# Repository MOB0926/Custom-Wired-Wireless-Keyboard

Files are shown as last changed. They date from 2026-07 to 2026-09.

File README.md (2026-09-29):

### Custom-Wired-Wireless-Keyboard

## What Is This?

- This is my entry for Hackclub's 'KEEB' YSWS

- I designed a Custom TKL keyboard. I designed a PCB and a 3D-Printed Case to house the PCB

- My keyboard features 80 Keys in the standard orientation and order of a keyboard. In addition to an EC11 Rotary encoder for Volume Adjustment and a 0.91 in OLED to display whatever I want. As the circuit is controlled by a WEMOS LOLIN ESP32 S3 Mini, I have included wireless functionality through its onboard BLE, along with an internal 18650 battery and charging unit to supply power during wireless use.

## Challenges 

- Price. PCBs over 100x100mm are very expensive, along with all the other components this may have been my most dificult project for finding cost effective solutions

- Size. The case is massive and no printer I own or have acces too will allow me to print this so I had to think about that as I designed.

- Procrastination. I had 3 months to do this and for some reason took like 3 week breaks in between entries at the begining

## What I learned

- This is my first time implementing a battery into a project so it was quite the new experience

- I have never designed or even built a Keyboard in my life (Excluding the Blueprint Hack-Pad) so I learnt a lot about how they work and the many different ways the case can come together.

- 3ple check every measurement before basing a design choice on it and then coming back after 4 hours of work just for it to be completetly wrong

## Why 

- Free Keyboard Obviously (Well if instead of putting all this time into this and I got a job instead I think I would have more than a $90 grant)

- Cool thing to show off

- Experience and knowledge for the future that will hopefully help me get a good career

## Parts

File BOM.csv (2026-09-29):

Item Desc | Link / Seller | qty | total price (USD)
Esp32-S3-Mini | https://www.aliexpress.com/item/3256805262904443.html?mp=1 | x1 | 06.39
Li-ion Bat Charger | https://www.aliexpress.com/item/3256806637067881.html?mp=1 | x1 | 02.75
1N148 Diodes SMD (100pc) | https://www.aliexpress.com/item/3256809295401623.html?mp=1 | x1 | 01.86
Switches (90pc) | https://www.aliexpress.com/item/3256806210108666.html?mp=1 | x1 | 13.21
Keycap Set (104pc) | https://www.aliexpress.com/item/3256811496795361.html?mp=1 | x1 | 08.12
M3x6 Screws (50pc) | https://www.aliexpress.com/item/3256808399236240.html?mp=1 | x1 | 00.99
EC11 Rotary Encoder | https://www.aliexpress.com/item/3256805940972786.html?mp=1 | x1 | 01.56
PCB (5pc) | JLCPCB.com | x1 | 26.90
Standofs (1x6.25u + 4x2u) | https://www.aliexpress.com/item/3256801500004993.html?mp=1 | x1 | 5.57
Shipping |  |  | 18.54
Total |  |  | 85.89

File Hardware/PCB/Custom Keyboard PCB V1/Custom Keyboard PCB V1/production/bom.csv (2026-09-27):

Designator | Footprint | Quantity | Value | LCSC Part #
D1, D10, D11, D12, D13, D14, D15, D16, D17, D18, D19, D2, D20, D21, D22, D23, D24, D25, D26, D27, D28, D29, D3, D30, D31, D32, D33, D34, D35, D36, D37, D38, D39, D4, D40, D41, D42, D43, D44, D45, D46, D47, D48, D49, D5, D50, D51, D52, D53, D54, D55, D56, D57, D58, D59, D6, D60, D61, D62, D63, D64, D65, D66, D67, D68, D69, D7, D70, D71, D72, D73, D74, D75, D76, D77, D78, D79, D8, D80, D9 | D_MiniMELF_Handsoldering | 80 | 1N4148
J1 | OLED_SSD1306_I2C_0.96 | 1 | Conn_01x04
J2, J3, J4, J5 | PinHeader_1x01_P2.54mm_Vertical | 4 | Conn_01x01
R1, R2, R3 | R_Axial_DIN0204_L3.6mm_D1.6mm_P5.08mm_Horizontal | 3 | 5k
S1, S2, S3, S4 | STAB_MX_P_2u | 4 | MX_stab
S5 | STAB_MX_P_6.25u | 1 | MX_stab
SW1, SW10, SW11, SW12, SW13, SW14, SW15, SW16, SW17, SW18, SW19, SW2, SW20, SW21, SW22, SW23, SW24, SW25, SW26, SW27, SW28, SW29, SW3, SW30, SW31, SW32, SW33, SW34, SW35, SW36, SW37, SW38, SW39, SW4, SW40, SW41, SW42, SW43, SW44, SW45, SW46, SW47, SW48, SW49, SW5, SW50, SW51, SW52, SW53, SW54, SW55, SW56, SW57, SW58, SW59, SW6, SW60, SW61, SW62, SW63, SW64, SW65, SW66, SW67, SW68, SW69, SW7, SW70, SW71, SW72, SW73, SW74, SW75, SW76, SW77, SW78, SW79, SW8, SW80, SW9 | SW_MX_1u | 80 | SW_Push
SW_EC11 | RotaryEncoder_Alps_EC11E-Switch_Vertical_H20mm_MountingHoles | 1 | RotaryEncoder_Switch_MP
U1 | WEMOS_S2_mini | 1 | WeMos_S3_mini

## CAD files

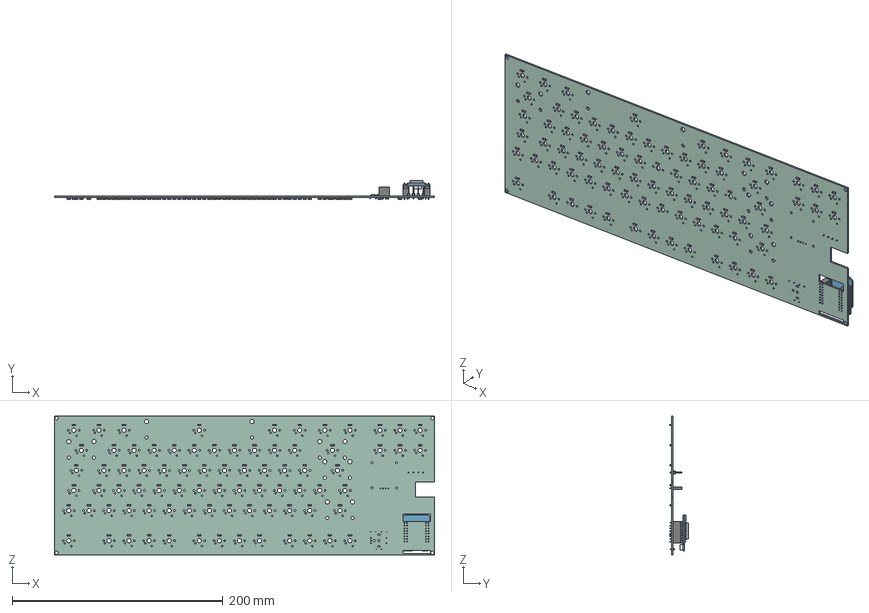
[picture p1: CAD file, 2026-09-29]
Hardware/Case/PCB 3D Model.step
360.5 x 17.7 x 131.8 mm

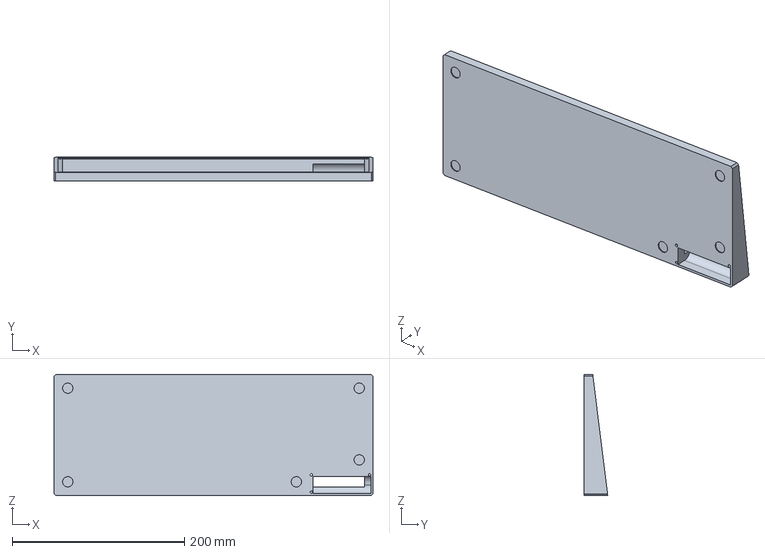
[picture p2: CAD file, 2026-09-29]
Hardware/Case/Case Bottom.step
370.5 x 27.4 x 140.7 mm

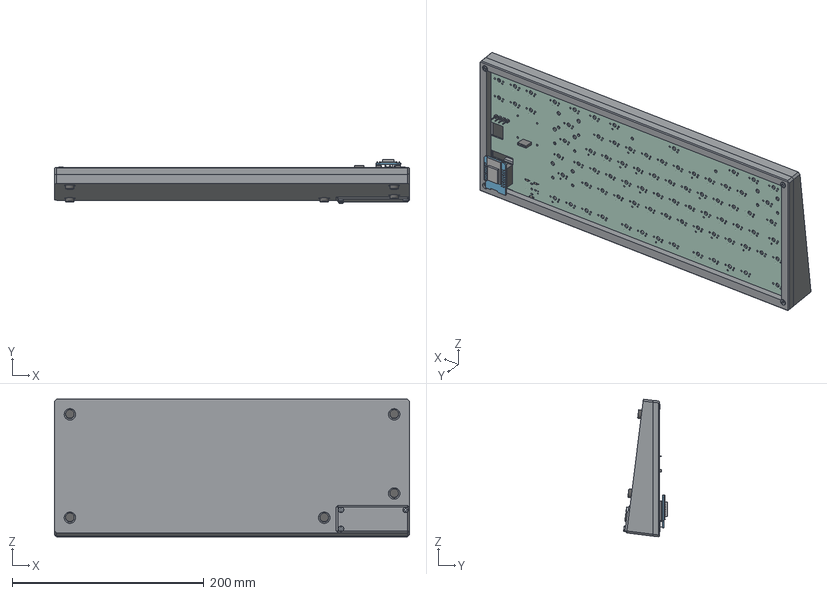
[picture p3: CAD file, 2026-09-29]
Hardware/Case/3D Model (Missing Keys + Caps).step
370.6 x 45.8 x 143.7 mm
D_MiniMELF_Standard_36
D_MiniMELF_Standard_52
D_MiniMELF_Standard_14
PinHeader_1x01_P254mm_Vertical_3
PinHeader_1x01_P254mm_Vertical
R_Axial_DIN0204_L36mm_D16mm_P508mm_Horizontal_2
D_MiniMELF_Standard_74
D_MiniMELF_Standard_69
D_MiniMELF_Standard_7
D_MiniMELF_Standard_6
D_MiniMELF_Standard_28
D_MiniMELF_Standard_61
D_MiniMELF_Standard_32
D_MiniMELF_Standard_67
D_MiniMELF_Standard_42
D_MiniMELF_Standard_26
D_MiniMELF_Standard_3
D_MiniMELF_Standard_72
D_MiniMELF_Standard_39
D_MiniMELF_Standard_49
D_MiniMELF_Standard_79
PinHeader_1x01_P254mm_Vertical_1
D_MiniMELF_Standard_60
D_MiniMELF_Standard_59
D_MiniMELF_Standard_43
R_Axial_DIN0204_L36mm_D16mm_P508mm_Horizontal_1
D_MiniMELF_Standard_15
D_MiniMELF_Standard_57
D_MiniMELF_Standard_13
D_MiniMELF_Standard_77
D_MiniMELF_Standard_4
D_MiniMELF_Standard_64
Hex socket head cap screw M3x0.50 x 6 x 6
D_MiniMELF_Standard_73
D_MiniMELF_Standard_35
D_MiniMELF_Standard_62
PinSocket_1x04_P2.54mm_Vertical
D_MiniMELF_Standard_75
D_MiniMELF_Standard_2
wemos_d1_mini_light
D_MiniMELF_Standard_53
D_MiniMELF_Standard_65
D_MiniMELF_Standard_70
D_MiniMELF_Standard_17
D_MiniMELF_Standard_40
D_MiniMELF_Standard_66
D_MiniMELF_Standard_56
D_MiniMELF_Standard_51
D_MiniMELF_Standard_10
D_MiniMELF_Standard_16
D_MiniMELF_Standard_48
D_MiniMELF_Standard_63
D_MiniMELF_Standard_11
D_MiniMELF_Standard_27
D_MiniMELF_Standard_47
D_MiniMELF_Standard_24
D_MiniMELF_Standard_12
D_MiniMELF_Standard_46
PinHeader_2x08_P254mm_Vertical_1
D_MiniMELF_Standard_18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

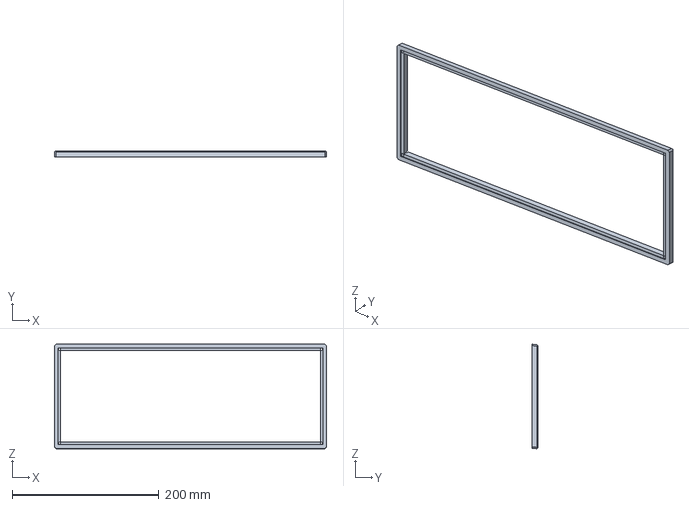
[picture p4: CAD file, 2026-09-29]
Hardware/Case/Case Top.step
370.5 x 7.50 x 142.6 mm

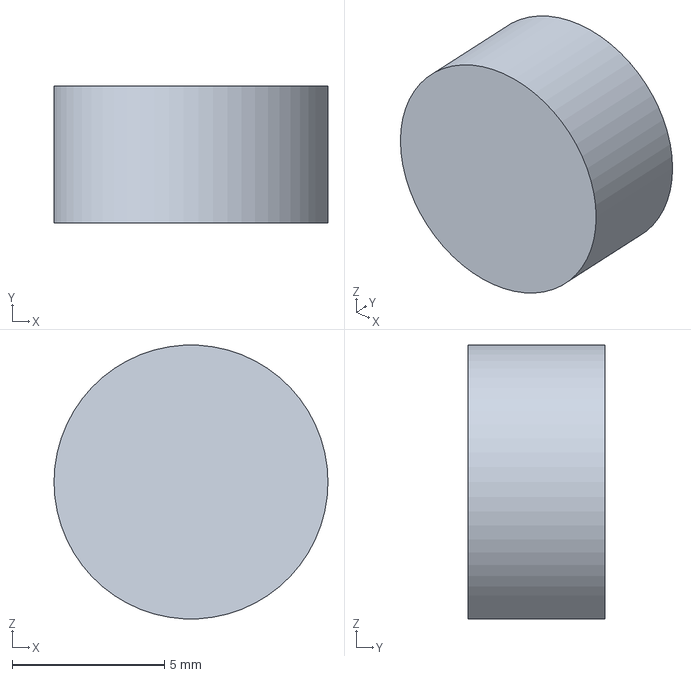
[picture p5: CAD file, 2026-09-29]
Hardware/Case/Feet.step
9.00 x 4.50 x 8.99 mm

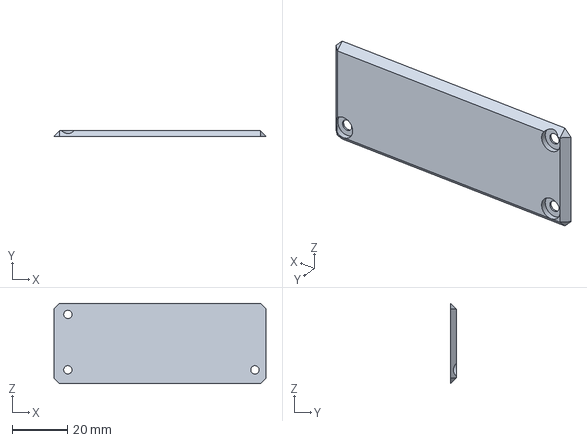
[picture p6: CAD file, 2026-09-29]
Hardware/Case/Battery Slot Cover.step
76.5 x 2.00 x 29.0 mm

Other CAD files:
Hardware/PCB/Custom Keyboard PCB V1/Custom Keyboard PCB V1/.step

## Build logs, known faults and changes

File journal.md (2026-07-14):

# Custom-Wired-Wireless-Keyboard
     
(Please forgive spelling mistakes, .md is not forgiving)

# Day 1 (6/25/26) (3 hours)
  
**Idea**
  
My plan is to make a keyboard (obviously), but I want to add wireless connectivity through an ESP32 S2 Mini board instead of the recomended RPI Pico.
    
Wireless requires power still so I will be implementing a battery (probably 18650) along with a charging module.
     
Im not certain on size yet. I do like larger keyboards, but that would complicate my design along with the need for space for my extra components.
   
Extra components: I have an extra 0.96 in oled lying around so I might add that. Additionally I might add an EC11 but im not sure what I would use it for yet.
   
**Progress**
    
For day 1 I first read through the docs then spend the majority of my time researching + adding things to my Ali Express cart.
   
The first thing I did was create my REPO but I only set it up untill the end with my desired format for my project.
   
**Plan for next day**
   
(Not tomorrow though because its my birthday and I will be too busy to make any progress)
   
Next up I think im going straight to working on the schematic and then I will see what else I need to do.

# Day 2 (6/26/26) (1 hour)
   
**Progress**
   
I did not do much this day I just had some free time where I did not feel like playing games so I just tried to find a footprint for the board im using. Long story short It barely exisxts and I suck at downloading stuf from any git platform. Additionally big blunder on me for doing little research, the EPS32 S2 does not feature BLE. Luckily Wemos sells the same footprint board but with and S3 chip and slightly differnt pinnout which I just eddited in KiCad. (Very OP keyboard now IG)

# Day 3 (7/4/26) (#? hours)

YAYYYY 4th of July AMERICAAAAAA FIREWOORKS (BOOOOOM BOOOOM BOOOOOOOOOM!!!!) 250 yrs 

Im in Gettysburg bored out of my mind so I'm working on a schematic yay :)

**Progress**
- EC11 Rotary Encoder + SW in schematic. Not 100% sure on use but im thinking cycling through RGB settings. We'll see
-

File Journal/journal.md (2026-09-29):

## Custom-Wired-Wireless-Keyboard
      
(Please forgive spelling mistakes, .md is not for the weak)

## Day 1 (6/25/26) (3 hours)
     
### Idea
     
- My plan is to make a keyboard (obviously), but I want to add wireless connectivity through an ESP32 S2 Mini board instead of the recomended RPI Pico.
     
- Wireless requires power still so I will be implementing a battery (probably 18650) along with a charging module.
     
- Im not certain on size yet. I do like larger keyboards, but that would complicate my design along with the need for space for my extra components.
   
- Extra components: I have an extra 0.96 in oled lying around so I might add that. Additionally I might add an EC11 but im not sure what I would use it for yet.
   
### Progress
    
- For day 1 I first read through the docs then spend the majority of my time researching + adding things to my Ali Express cart.
   
- The first thing I did was create my REPO but I only set it up untill the end with my desired format for my project.
   
### What's Next?
      
- Next up I think im going straight to working on the schematic and then I will see what else I need to do.

## Day 2 (6/26/26) (1 hour)
     
### Progress
     
- I did not do much this day I just had some free time where I did not feel like playing games so I just tried to find a footprint for the board im using. Long story short It barely exisxts and I suck at downloading stuf from any git platform. Additionally big blunder on me for doing little research, the EPS32 S2 does not feature BLE. Luckily Wemos sells the same footprint board but with and S3 chip and slightly differnt pinnout which I just eddited in KiCad. (Very OP keyboard now IG)
     
### Proof
   
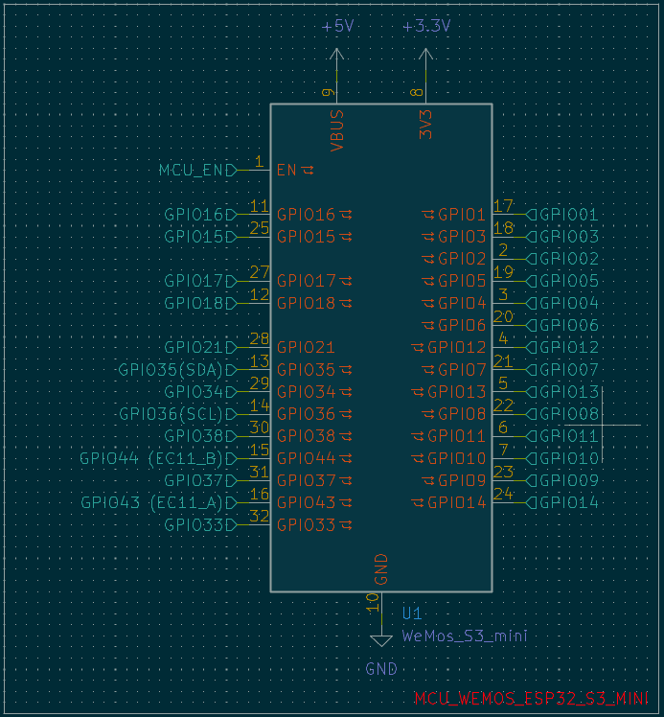
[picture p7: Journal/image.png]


## Day 3 (7/4/26) (4 hours)
    
### Progress
    
- EC11 Rotary Encoder + SW in schematic. Not 100% sure on use but im thinking cycling through RGB settings. We'll see
- Created Keyboard Matrix file in Hierarchy
- Added pin headder for 4 pin I2C 0.96in OLED
- Added pins for Battery Module (Not yet sure on footprint so will come back)
    
### Proof
    
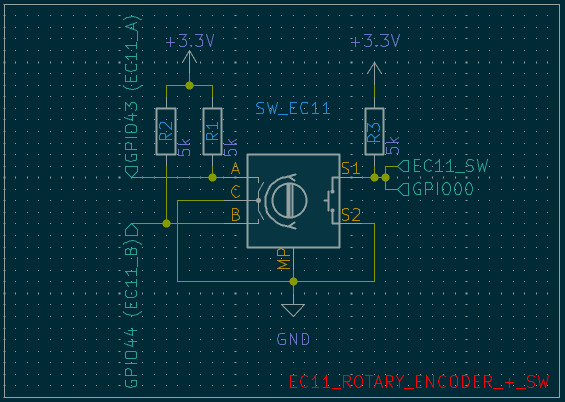
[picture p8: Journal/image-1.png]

    
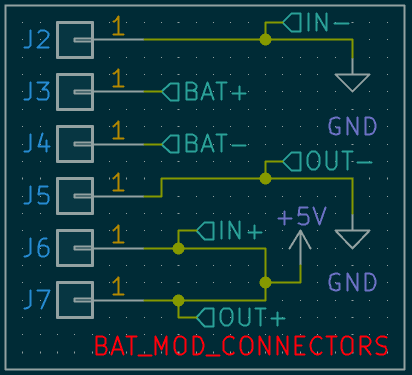
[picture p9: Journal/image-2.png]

    
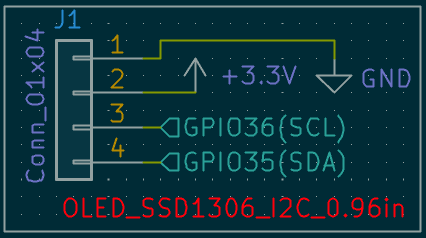
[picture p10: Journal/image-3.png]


### What's Next?

- Continue working on Matrix

## Day 4 (7/14/26) (4 hours)
    
### Progress
        
- Removed Heirarchical sheets (Had some errors and realized it fit on the main sheet anyways so I just fit it all together)
- Finished Schematic Draft
- Added stabilizers
- Planing Key Layout (used [keyboard-layout-editor](https://www.keyboard-layout-editor.com/). My idea is basically a TKL but without a few of the extra keys to the side that i litterally never use in order to get space for the rest of my components)
    
### Proof
       
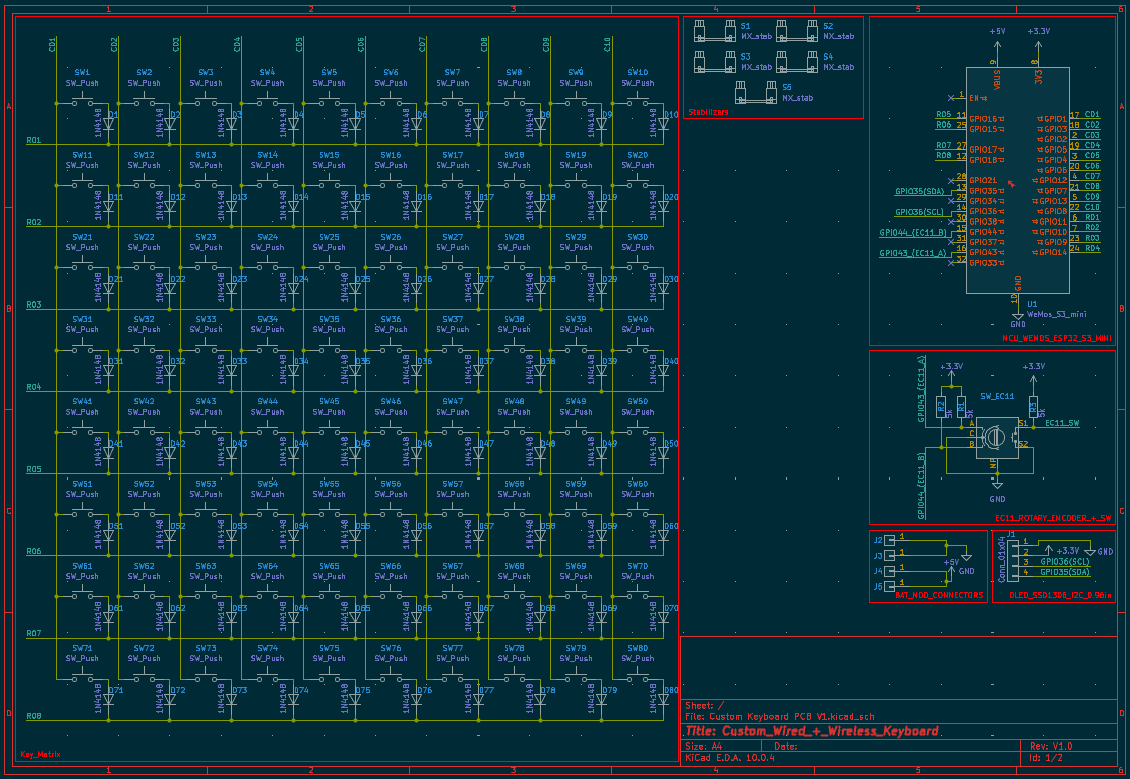
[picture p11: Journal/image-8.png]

      
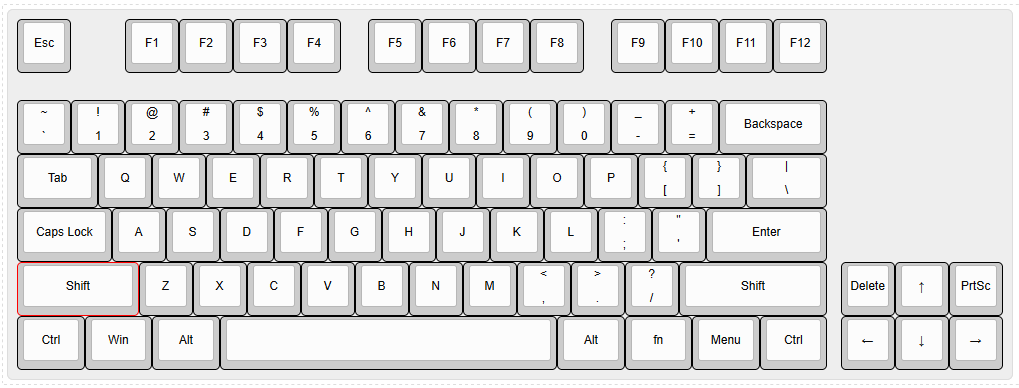
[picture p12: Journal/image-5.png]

      
### What's Next?
      
- Review Schematic
- Finalize Footprints
- Beging PCB Layout
      
## Day 5 (8/5/26) (4 hours)
      
### Progress
      
- I figured out how I will lay out the keys. Originally I was lost, I tried a few methods but ended up getting stuck at different points both with my lack of experience with kicad's ackwardness with moving components sometimes and kind of not understanding / wanting to use automatic layout tools. After all that I just decided I would layout manually by first laying out the keys in the pattern I desired and then coming back to propperly space them. Basically for spacing I set set my spacing to 19.05mm and for keys that were not 1u I used (shift+p) or (Right click > Positioning Tools > Position Relative to Reference Item) then hit "Select Point..." to my reference switch and spaced it out as 19.05mm for 1u or the (u size of the key + 1u (key size)) / 2 x 19.05 for bigger keys, and then angle is the direction. Example for 1.5u key = ((1.5u + 1u) / 2) x 19.05 = 1.25
      
### Proof
      
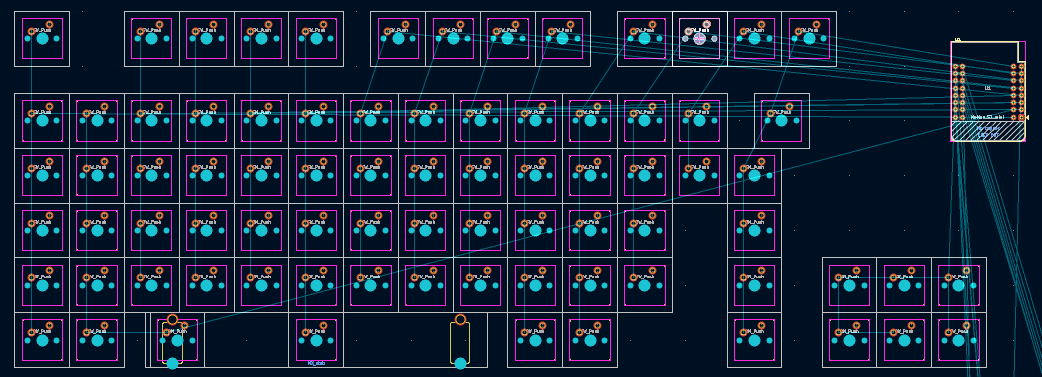
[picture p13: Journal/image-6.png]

      
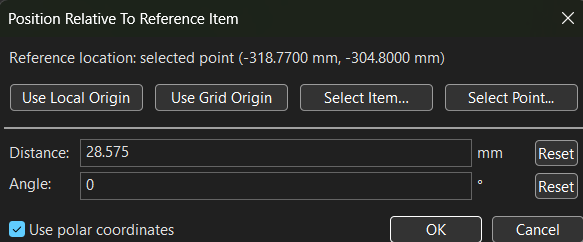
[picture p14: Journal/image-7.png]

      
### What's Next?
      
- Finish switch layout and the rest of my placements before wiring the pcb

## Day 6 (Compilation of multiple days that I forgot to update jurnal for)
       
### Progress
      
- Finished key layout, diode placement, and all of the wire routing. So basically I am done with the PCB
Did not end up going for the LED's. I left it for the side for too long and now to go back would be a very long process and I need to get this project done soon.
      
### Proof
      
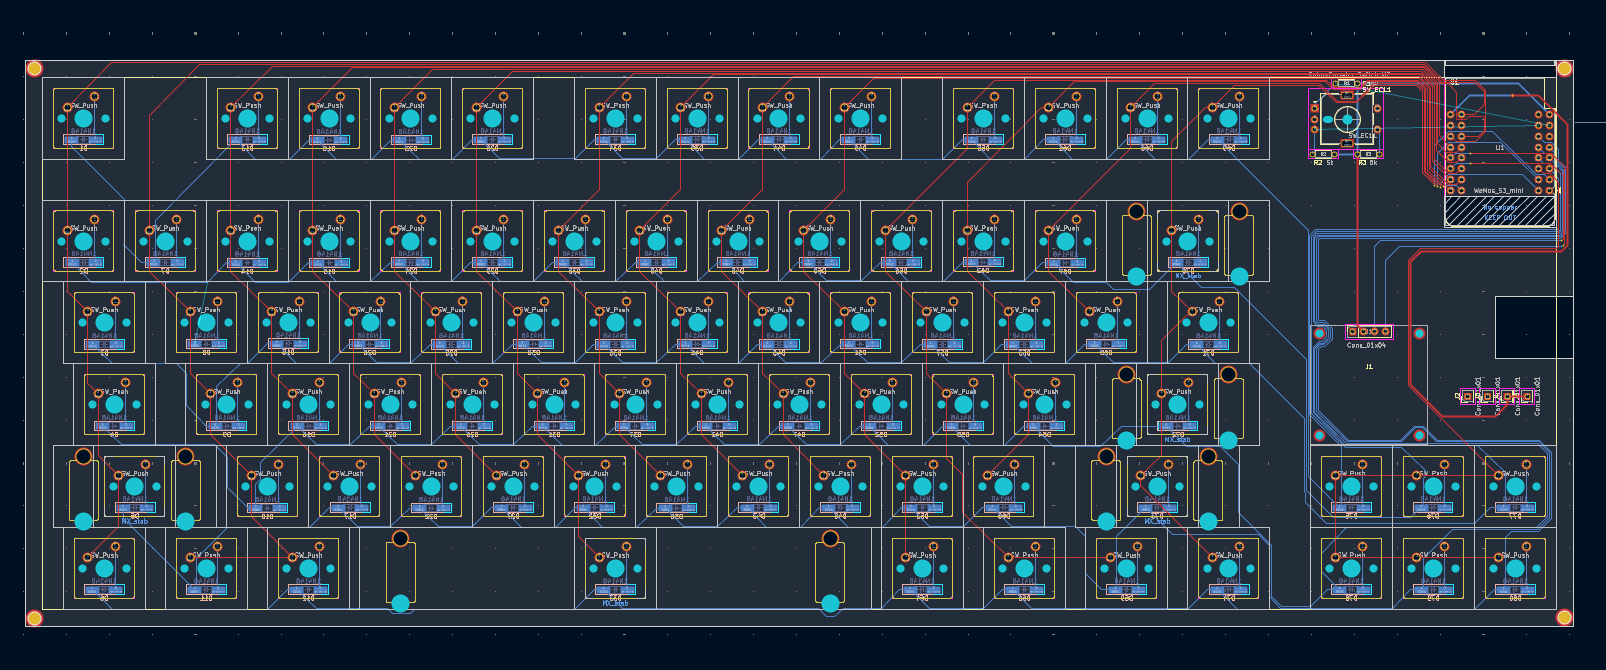
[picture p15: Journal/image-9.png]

      
### What's Next?
      
- Case CAD

## Day 7 (9/26/26) (>4 hours)
       
### Progress
      
- CAD :(  I got the case mostly done. + I fixed some mistakes on the PCB (GND fill was not set to connect to the GND pads)
      
### Proof
      
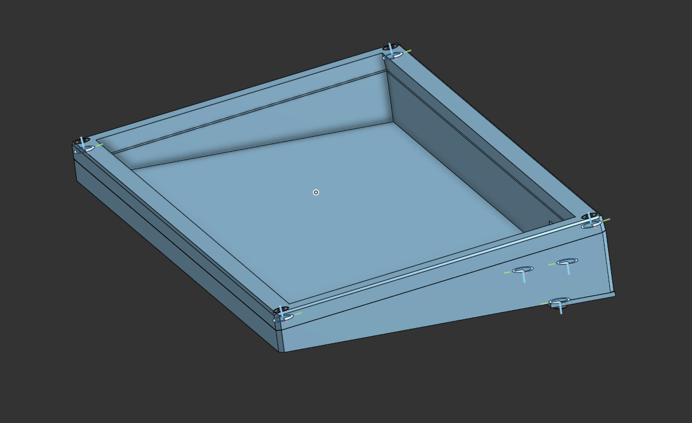
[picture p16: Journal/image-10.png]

      
### What's Next?
      
- I will soon realize the Plate is wrong for the cad and that will kind of ruin my day so I will stop and come back the next day to fix it

## Day 8 (9/27/26) (3 Hours)
       
### Progress
      
- I do not have enough time to redo the plate (keeb done in 3 days) in the cad so the plan is to skip the plate and use the PCB as the plate (realistically will be more stable than the 1.5mm PLA plate)
        
- Also Vibecoded some of the code for the keyboard (I am 100% certain it will not work and I will have to come back to fix it so wtvr i just need to submit)
       
- Also updated BOM
      
### Proof
      
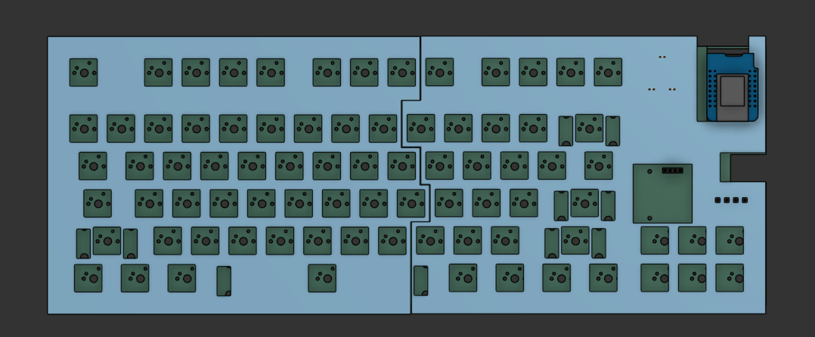
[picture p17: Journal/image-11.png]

     
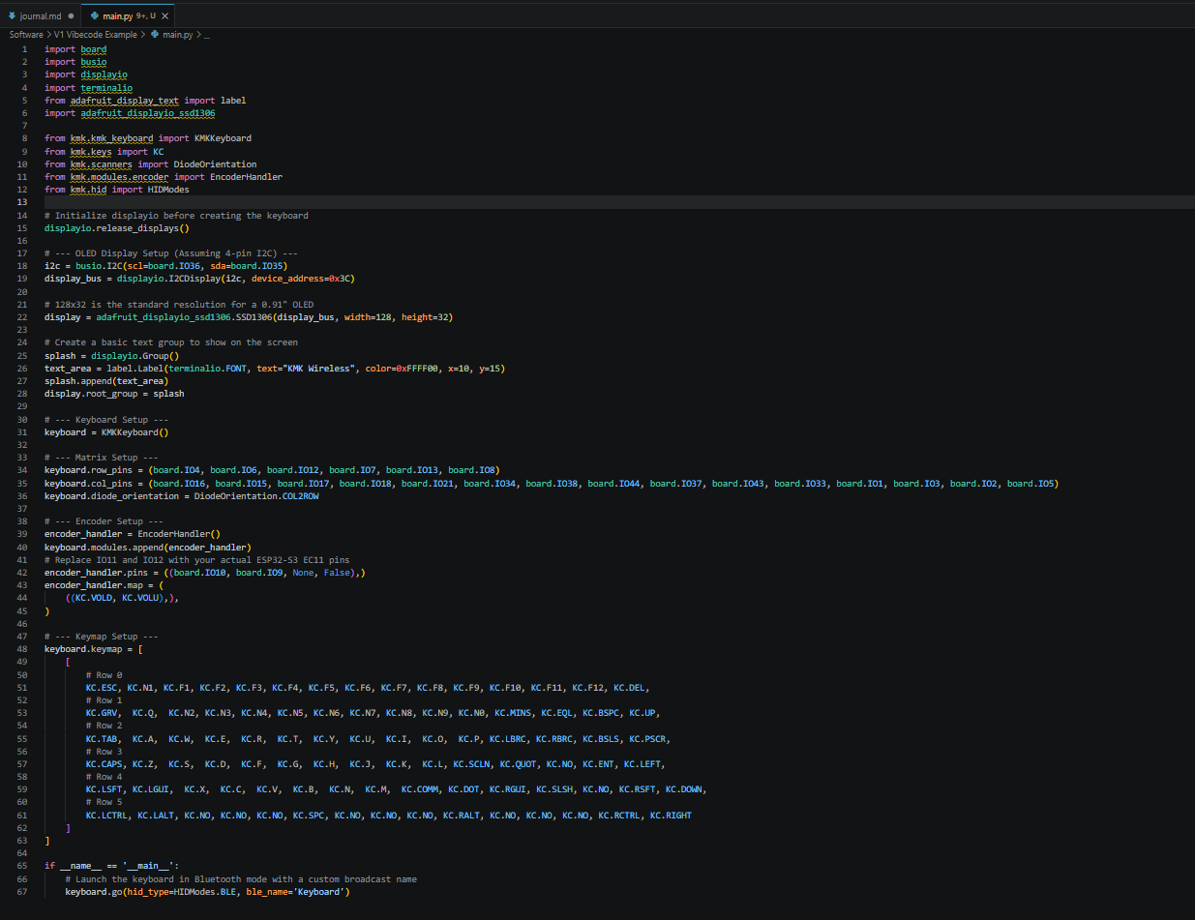
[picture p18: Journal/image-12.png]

      
### What's Next?
      
- Fix CAD

## Day 9 (9/28/26) (3 Hours)
       
### Progress
      
- CAD fixed and complete
       
- Also updated BOM
      
### Proof
       
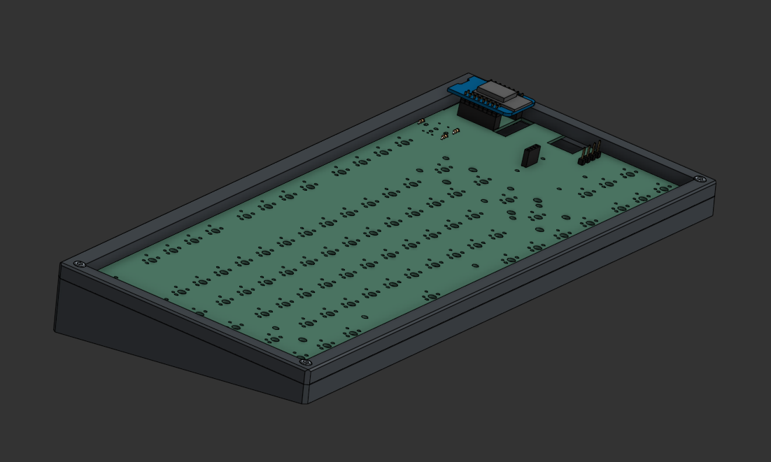
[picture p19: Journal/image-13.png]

            
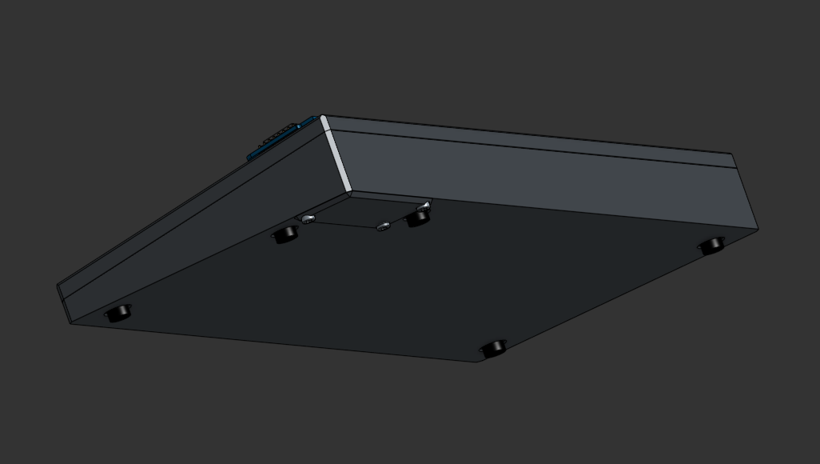
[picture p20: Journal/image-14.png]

       
### What's Next?
      
- SUBMIT SUBMIT SUBMIT SUBMIT (Obv review first)

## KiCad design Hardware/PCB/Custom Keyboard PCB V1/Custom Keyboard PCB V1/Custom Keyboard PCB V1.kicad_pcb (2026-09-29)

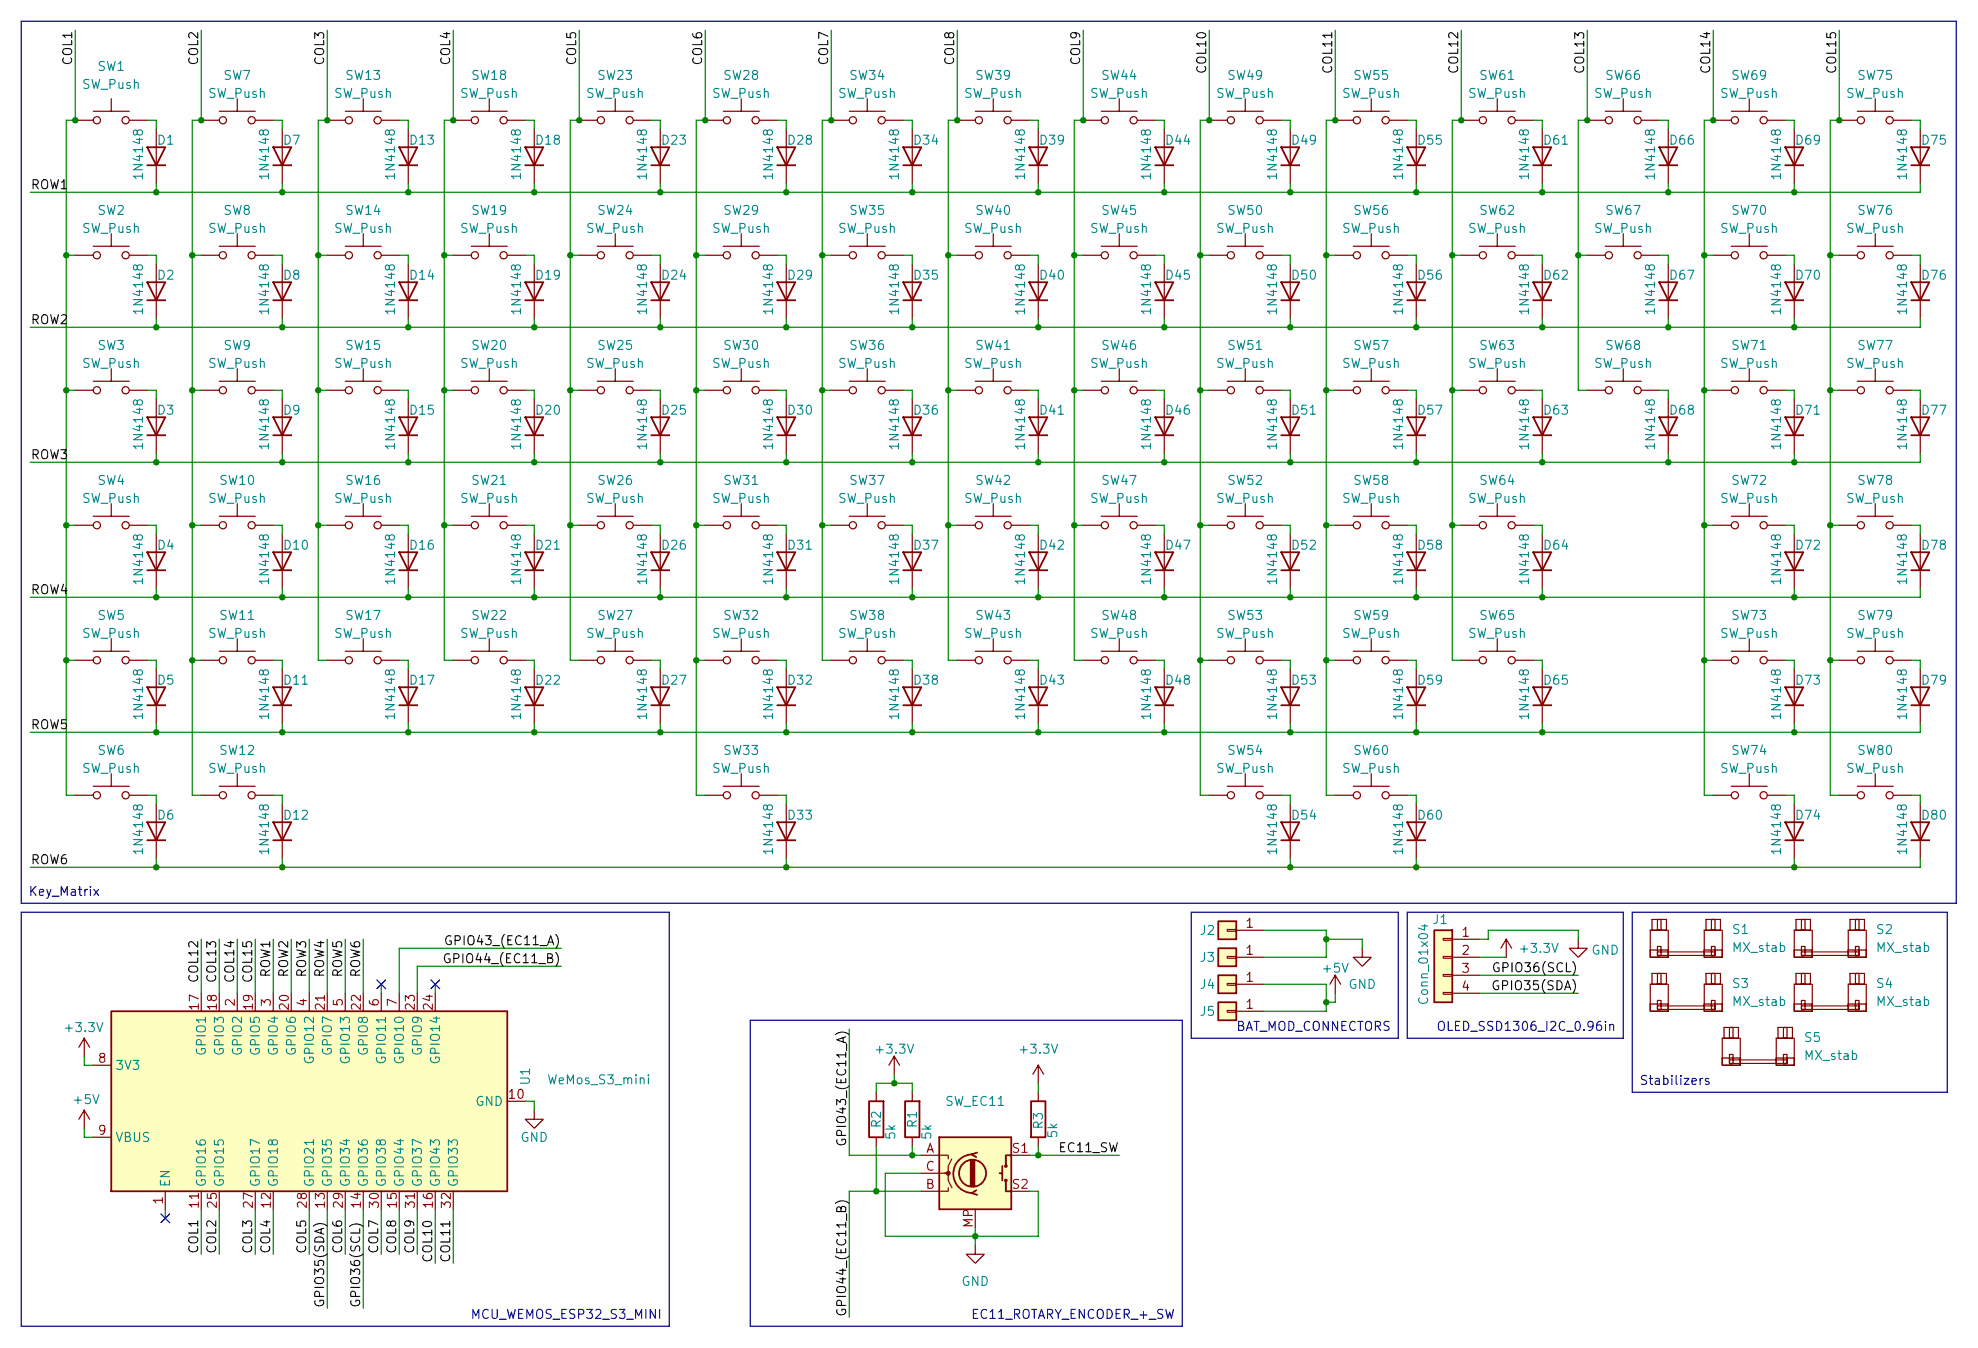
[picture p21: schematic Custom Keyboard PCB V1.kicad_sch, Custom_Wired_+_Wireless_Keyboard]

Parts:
D1, D2, D3, D4, D5, D6, D7, D8, D9, D10, D11, D12, D13, D14, D15, D16, D17, D18, D19, D20, D21, D22, D23, D24, D25, D26, D27, D28, D29, D30, D31, D32, D33, D34, D35, D36, D37, D38, D39, D40, D41, D42, D43, D44, D45, D46, D47, D48, D49, D50, D51, D52, D53, D54, D55, D56, D57, D58, D59, D60, D61, D62, D63, D64, D65, D66, D67, D68, D69, D70, D71, D72, D73, D74, D75, D76, D77, D78, D79, D80: 1N4148; D_MiniMELF_Handsoldering
J1: Conn_01x04; OLED_SSD1306_I2C_0.96
J2, J3, J4, J5: Conn_01x01; PinHeader_1x01_P2.54mm_Vertical
R1, R2, R3: 5k; R_Axial_DIN0204_L3.6mm_D1.6mm_P5.08mm_Horizontal
S1, S2, S3, S4: MX_stab; STAB_MX_P_2u
S5: MX_stab; STAB_MX_P_6.25u
SW1, SW2, SW3, SW4, SW5, SW6, SW7, SW8, SW9, SW10, SW11, SW12, SW13, SW14, SW15, SW16, SW17, SW18, SW19, SW20, SW21, SW22, SW23, SW24, SW25, SW26, SW27, SW28, SW29, SW30, SW31, SW32, SW33, SW34, SW35, SW36, SW37, SW38, SW39, SW40, SW41, SW42, SW43, SW44, SW45, SW46, SW47, SW48, SW49, SW50, SW51, SW52, SW53, SW54, SW55, SW56, SW57, SW58, SW59, SW60, SW61, SW62, SW63, SW64, SW65, SW66, SW67, SW68, SW69, SW70, SW71, SW72, SW73, SW74, SW75, SW76, SW77, SW78, SW79, SW80: SW_Push; SW_MX_1u
SW_EC11: RotaryEncoder_Switch_MP; RotaryEncoder_Alps_EC11E-Switch_Vertical_H20mm_MountingHoles
U1: WeMos_S3_mini; WEMOS_S2_mini

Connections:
+3.3V: J1.2, R1.2, R2.2, R3.1, U1.8 (3V3)
+5V: J4.1 (Pin_1_1), J5.1 (Pin_1_1), U1.9 (VBUS)
/COL1: SW1.1, SW2.1, SW3.1, SW4.1, SW5.1, SW6.1, U1.11 (GPIO16)
/COL2: SW7.1, SW8.1, SW9.1, SW10.1, SW11.1, SW12.1, U1.25 (GPIO15)
/COL3: SW13.1, SW14.1, SW15.1, SW16.1, SW17.1, U1.27 (GPIO17)
/COL4: SW18.1, SW19.1, SW20.1, SW21.1, SW22.1, U1.12 (GPIO18)
/COL5: SW23.1, SW24.1, SW25.1, SW26.1, SW27.1, U1.28 (GPIO21)
/COL6: SW28.1, SW29.1, SW30.1, SW31.1, SW32.1, SW33.1, U1.29 (GPIO34)
/COL7: SW34.1, SW35.1, SW36.1, SW37.1, SW38.1, U1.30 (GPIO38)
/COL8: SW39.1, SW40.1, SW41.1, SW42.1, SW43.1, U1.15 (GPIO44)
/COL9: SW44.1, SW45.1, SW46.1, SW47.1, SW48.1, U1.31 (GPIO37)
/COL10: SW49.1, SW50.1, SW51.1, SW52.1, SW53.1, SW54.1, U1.16 (GPIO43)
/COL11: SW55.1, SW56.1, SW57.1, SW58.1, SW59.1, SW60.1, U1.32 (GPIO33)
/COL12: SW61.1, SW62.1, SW63.1, SW64.1, SW65.1, U1.17 (GPIO1)
/COL13: SW66.1, SW67.1, SW68.1, U1.18 (GPIO3)
/COL14: SW69.1, SW70.1, SW71.1, SW72.1, SW73.1, SW74.1, U1.2 (GPIO2)
/COL15: SW75.1, SW76.1, SW77.1, SW78.1, SW79.1, SW80.1, U1.19 (GPIO5)
/EC11_SW: R3.2, SW_EC11.S1
/GPIO35(SDA): J1.4, U1.13 (GPIO35)
/GPIO36(SCL): J1.3, U1.14 (GPIO36)
/GPIO43_(EC11_A): R1.1, SW_EC11.A, U1.7 (GPIO10)
/GPIO44_(EC11_B): R2.1, SW_EC11.B, U1.23 (GPIO9)
/ROW1: D1.1 (K), D7.1 (K), D13.1 (K), D18.1 (K), D23.1 (K), D28.1 (K), D34.1 (K), D39.1 (K), D44.1 (K), D49.1 (K), D55.1 (K), D61.1 (K), D66.1 (K), D69.1 (K), D75.1 (K), U1.3 (GPIO4)
/ROW2: D2.1 (K), D8.1 (K), D14.1 (K), D19.1 (K), D24.1 (K), D29.1 (K), D35.1 (K), D40.1 (K), D45.1 (K), D50.1 (K), D56.1 (K), D62.1 (K), D67.1 (K), D70.1 (K), D76.1 (K), U1.20 (GPIO6)
/ROW3: D3.1 (K), D9.1 (K), D15.1 (K), D20.1 (K), D25.1 (K), D30.1 (K), D36.1 (K), D41.1 (K), D46.1 (K), D51.1 (K), D57.1 (K), D63.1 (K), D68.1 (K), D71.1 (K), D77.1 (K), U1.4 (GPIO12)
/ROW4: D4.1 (K), D10.1 (K), D16.1 (K), D21.1 (K), D26.1 (K), D31.1 (K), D37.1 (K), D42.1 (K), D47.1 (K), D52.1 (K), D58.1 (K), D64.1 (K), D72.1 (K), D78.1 (K), U1.21 (GPIO7)
/ROW5: D5.1 (K), D11.1 (K), D17.1 (K), D22.1 (K), D27.1 (K), D32.1 (K), D38.1 (K), D43.1 (K), D48.1 (K), D53.1 (K), D59.1 (K), D65.1 (K), D73.1 (K), D79.1 (K), U1.5 (GPIO13)
/ROW6: D6.1 (K), D12.1 (K), D33.1 (K), D54.1 (K), D60.1 (K), D74.1 (K), D80.1 (K), U1.22 (GPIO8)
GND: J1.1, J2.1 (Pin_1_1), J3.1 (Pin_1_1), SW_EC11.C, SW_EC11.MP, SW_EC11.S2, U1.10 (GND), U1.26 (GND)
unnamed: D1.2 (A), SW1.2
unnamed: D2.2 (A), SW2.2
unnamed: D3.2 (A), SW3.2
unnamed: D4.2 (A), SW4.2
unnamed: D5.2 (A), SW5.2
unnamed: D6.2 (A), SW6.2
unnamed: D7.2 (A), SW7.2
unnamed: D8.2 (A), SW8.2
unnamed: D9.2 (A), SW9.2
unnamed: D10.2 (A), SW10.2
unnamed: D11.2 (A), SW11.2
unnamed: D12.2 (A), SW12.2
unnamed: D13.2 (A), SW13.2
unnamed: D14.2 (A), SW14.2
unnamed: D15.2 (A), SW15.2
unnamed: D16.2 (A), SW16.2
unnamed: D17.2 (A), SW17.2
unnamed: D18.2 (A), SW18.2
unnamed: D19.2 (A), SW19.2
unnamed: D20.2 (A), SW20.2
unnamed: D21.2 (A), SW21.2
unnamed: D22.2 (A), SW22.2
unnamed: D23.2 (A), SW23.2
unnamed: D24.2 (A), SW24.2
unnamed: D25.2 (A), SW25.2
unnamed: D26.2 (A), SW26.2
unnamed: D27.2 (A), SW27.2
unnamed: D28.2 (A), SW28.2
unnamed: D29.2 (A), SW29.2
unnamed: D30.2 (A), SW30.2
unnamed: D31.2 (A), SW31.2
unnamed: D32.2 (A), SW32.2
unnamed: D33.2 (A), SW33.2
unnamed: D34.2 (A), SW34.2
unnamed: D35.2 (A), SW35.2
unnamed: D36.2 (A), SW36.2
unnamed: D37.2 (A), SW37.2
unnamed: D38.2 (A), SW38.2
unnamed: D39.2 (A), SW39.2
unnamed: D40.2 (A), SW40.2
unnamed: D41.2 (A), SW41.2
unnamed: D42.2 (A), SW42.2
unnamed: D43.2 (A), SW43.2
unnamed: D44.2 (A), SW44.2
unnamed: D45.2 (A), SW45.2
unnamed: D46.2 (A), SW46.2
unnamed: D47.2 (A), SW47.2
unnamed: D48.2 (A), SW48.2
unnamed: D49.2 (A), SW49.2
unnamed: D50.2 (A), SW50.2
unnamed: D51.2 (A), SW51.2
unnamed: D52.2 (A), SW52.2
unnamed: D53.2 (A), SW53.2
unnamed: D54.2 (A), SW54.2
unnamed: D55.2 (A), SW55.2
unnamed: D56.2 (A), SW56.2
unnamed: D57.2 (A), SW57.2
unnamed: D58.2 (A), SW58.2
unnamed: D59.2 (A), SW59.2
unnamed: D60.2 (A), SW60.2
unnamed: D61.2 (A), SW61.2
unnamed: D62.2 (A), SW62.2
unnamed: D63.2 (A), SW63.2
unnamed: D64.2 (A), SW64.2
unnamed: D65.2 (A), SW65.2
unnamed: D66.2 (A), SW66.2
unnamed: D67.2 (A), SW67.2
unnamed: D68.2 (A), SW68.2
unnamed: D69.2 (A), SW69.2
unnamed: D70.2 (A), SW70.2
unnamed: D71.2 (A), SW71.2
unnamed: D72.2 (A), SW72.2
unnamed: D73.2 (A), SW73.2
unnamed: D74.2 (A), SW74.2
unnamed: D75.2 (A), SW75.2
unnamed: D76.2 (A), SW76.2
unnamed: D77.2 (A), SW77.2
unnamed: D78.2 (A), SW78.2
unnamed: D79.2 (A), SW79.2
unnamed: D80.2 (A), SW80.2

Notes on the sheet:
OLED_SSD1306_I2C_0.96in
BAT_MOD_CONNECTORS
MCU_WEMOS_ESP32_S3_MINI
Key_Matrix
EC11_ROTARY_ENCODER_+_SW
Stabilizers

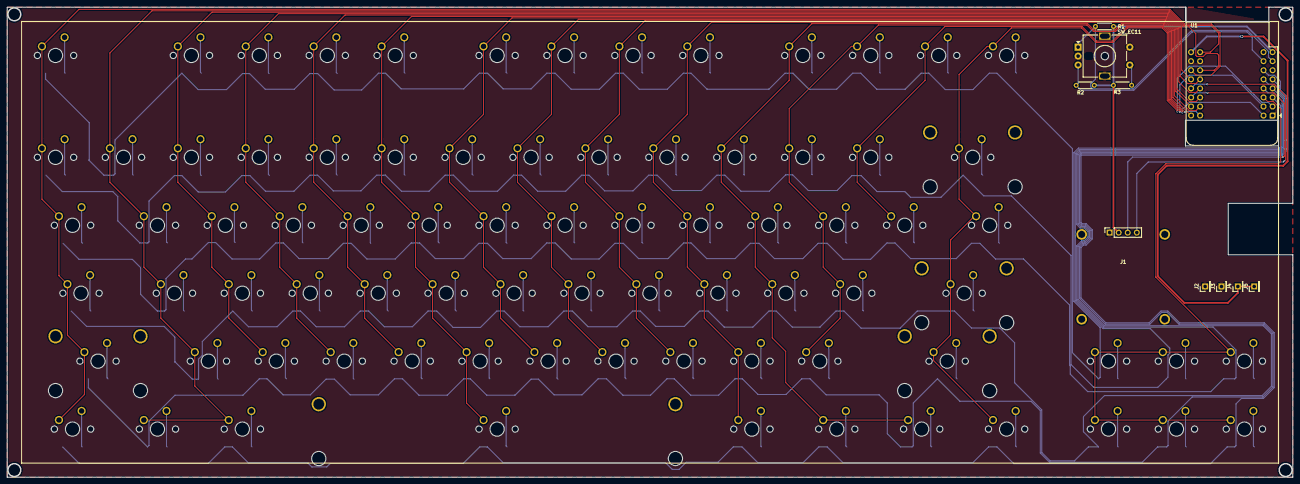
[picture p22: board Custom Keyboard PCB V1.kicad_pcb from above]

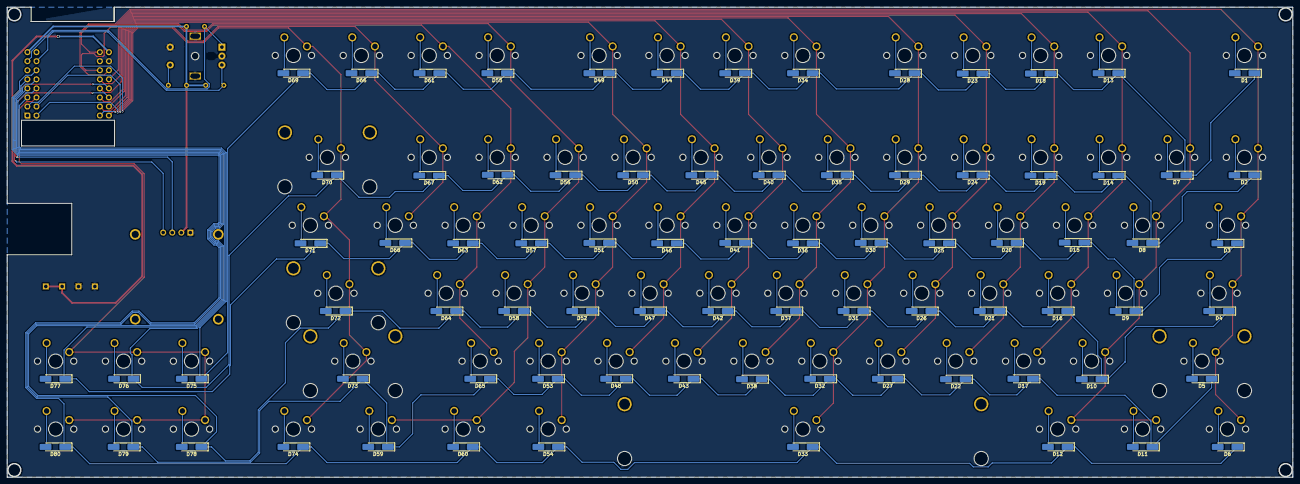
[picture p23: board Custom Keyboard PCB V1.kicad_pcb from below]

Board: 2 copper layers, 360.5 x 131.8 mm, 175 parts (80 on the bottom side), 109 nets.

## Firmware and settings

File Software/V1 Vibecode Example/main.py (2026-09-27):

import board
import busio
import displayio
import terminalio
from adafruit_display_text import label
import adafruit_displayio_ssd1306

from kmk.kmk_keyboard import KMKKeyboard
from kmk.keys import KC
from kmk.scanners import DiodeOrientation
from kmk.modules.encoder import EncoderHandler
from kmk.hid import HIDModes

# Initialize displayio before creating the keyboard
displayio.release_displays()

# --- OLED Display Setup (Assuming 4-pin I2C) ---
i2c = busio.I2C(scl=board.IO36, sda=board.IO35)
display_bus = displayio.I2CDisplay(i2c, device_address=0x3C)

# 128x32 is the standard resolution for a 0.91" OLED
display = adafruit_displayio_ssd1306.SSD1306(display_bus, width=128, height=32)

# Create a basic text group to show on the screen
splash = displayio.Group()
text_area = label.Label(terminalio.FONT, text="KMK Wireless", color=0xFFFF00, x=10, y=15)
splash.append(text_area)
display.root_group = splash

# --- Keyboard Setup ---
keyboard = KMKKeyboard()

# --- Matrix Setup ---
keyboard.row_pins = (board.IO4, board.IO6, board.IO12, board.IO7, board.IO13, board.IO8)
keyboard.col_pins = (board.IO16, board.IO15, board.IO17, board.IO18, board.IO21, board.IO34, board.IO38, board.IO44, board.IO37, board.IO43, board.IO33, board.IO1, board.IO3, board.IO2, board.IO5)
keyboard.diode_orientation = DiodeOrientation.COL2ROW

# --- Encoder Setup ---
encoder_handler = EncoderHandler()
keyboard.modules.append(encoder_handler)
# Replace IO11 and IO12 with your actual ESP32-S3 EC11 pins
encoder_handler.pins = ((board.IO10, board.IO9, None, False),)
encoder_handler.map = (
    ((KC.VOLD, KC.VOLU),), 
)

# --- Keymap Setup ---
keyboard.keymap = [
    [
        # Row 0
        KC.ESC, KC.N1, KC.F1, KC.F2, KC.F3, KC.F4, KC.F5, KC.F6, KC.F7, KC.F8, KC.F9, KC.F10, KC.F11, KC.F12, KC.DEL,
        # Row 1
        KC.GRV,  KC.Q,  KC.N2, KC.N3, KC.N4, KC.N5, KC.N6, KC.N7, KC.N8, KC.N9, KC.N0, KC.MINS, KC.EQL, KC.BSPC, KC.UP,
        # Row 2
        KC.TAB,  KC.A,  KC.W,  KC.E,  KC.R,  KC.T,  KC.Y,  KC.U,  KC.I,  KC.O,  KC.P, KC.LBRC, KC.RBRC, KC.BSLS, KC.PSCR,
        # Row 3
        KC.CAPS, KC.Z,  KC.S,  KC.D,  KC.F,  KC.G,  KC.H,  KC.J,  KC.K,  KC.L, KC.SCLN, KC.QUOT, KC.NO, KC.ENT, KC.LEFT,
        # Row 4
        KC.LSFT, KC.LGUI,  KC.X,  KC.C,  KC.V,  KC.B,  KC.N,  KC.M,  KC.COMM, KC.DOT, KC.RGUI, KC.SLSH, KC.NO, KC.RSFT, KC.DOWN,
        # Row 5
        KC.LCTRL, KC.LALT, KC.NO, KC.NO, KC.NO, KC.SPC, KC.NO, KC.NO, KC.NO, KC.RALT, KC.NO, KC.NO, KC.NO, KC.RCTRL, KC.RIGHT
    ]
]

if __name__ == '__main__':
    # Launch the keyboard in Bluetooth mode with a custom broadcast name
    keyboard.go(hid_type=HIDModes.BLE, ble_name='Keyboard')

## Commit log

2026-08-26 might be broken
    [Custom Keyboard PCB V1.kicad_pcb, Custom Keyboard PCB V1.kicad_sch]
2026-08-29 i guess maybe not broken
    [Custom Keyboard PCB V1.kicad_pcb, Custom Keyboard PCB V1.kicad_sch]
2026-09-29 Final I think
    Not really but a least final before I submit
    [3D Model (Missing Keys + Caps).step, BOM.csv, Battery Slot Cover.step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]
2026-10-31 IDK anymore
    Changed day 6 date / time
    Added CAD Link
2026-11-06 Fixes
    submission return so updated with fixes
    - Added PCB and Schematic Pics to README.md
    - Resized PCB border
2026-11-06 broke
    fixed duplicate day 9 and renamed production zip to gerbers.zip bc required by fab
